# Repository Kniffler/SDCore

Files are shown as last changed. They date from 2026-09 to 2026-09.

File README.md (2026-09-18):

# SDCore
So I went and made an entire SD card because I thought my PicoCalc didn't have enough juice.

## IMPORTANT (READ THIS)
Please read through the entire README in order to get a grasp of the limitations of this project since they might save your skin while developing.

TL;DR: [Restrictions summary](#restrictions-summary)

### Also important
I am not responsible for your usage or misusage of this project.

## Specs
This SD core is based on the RP2350A by raspberry pi and features:
- Hardware-level control of the routing of the SD pins
- 3 state-indicating LEDs (power, program, and select)
- 16MiB of flash
- A micro-SD card slot
- Additional GPIO output (see below)
- An access point for USB programming when setting pin 6 to 3.3V

Annoyingly, when using the edge connector and the micro-SD card slot at the same time, no SPI interface will be left to use on the device, nor will the corresponding pins (see [pinout](#pinout)) be available for anything else.

# Images
None yet, we'll see when the order arrives.

# Hardware pin control
I added a tri-state demultiplexer ([NMUX27518EPWJ](https://assets.nexperia.com/documents/data-sheet/NMUX27518E.pdf)) to switch between 2 modes, direct transfer mode and sniffing mode (default is direct transfer mode). In direct transfer mode, the data0-data3, CLK and CMD pins from the edge connector are all mapped to the RP2350A and set up for communication via **SPI1**. While sniffing mode also maps the edge connector to the MCU, it does so via **SPI0** and also directs them towards the micro-SD card slot allowing the MCU to sniff/spy on the communication between the host device and the micro-SD card.

> [!IMPORTANT]
> When using direct transfer mode, SPI1 is used and in sniffing mode we use SPI0. The pinouts are inherently different. Please look at the [pinout](#pinout) section for details.

The different SPI controllers are utilized in order to communicate with the host and the micro-SD card separately and/or simultaneously.

# How to program the RP2350A
There are 2 main scenarios, either you have the programmer board, or you don't. In the case that you do, connect the USB-C port to your PC or laptop, plug the SD core into the programmer board while holding the button on the board, once you see the USB mass storage on your PC (which you have presumably plugged into the programmer board already) you can release the button.

If you do not own a programmer board, (though it is highly recommended that you do) you can order one with the given gerber, BOM and P&P files which can be found in the `SDCore_progBoard/prodution` folder which also holds a few key values for ordering with PCB Assembly on [JLCPCB](jlcpcb.com).

> [!NOTE]
> The `.zip` file is the compressed gerber files, `bom.csv` is the BOM and `positions.csv` is the P&P file.

If ordering this PCB is not an option, please continue in the subsection below.

## Making a programmer board at home
You'll need:
- A reliable 3.3V power source
- A switch
- A breakout board of any USB end (male or female, type-A or type-C, whichever you can use to plug into your PC) with a D- and a D+ pin. If there are multiple of each, short them such that you only have **one** D- and **one** D+
- A breakout board of a **standard SD card** with ALL of these pins present: 3 (VSS/GND), 4 (VDD/3V3), 6 (the magic pin), 8 (DAT1) and 9 (DAT2) - other pins are optional

> [!WARNING]
> If any of these SD pins are missing from the breakout, you will not be able to program your SDCore.

If you don't have an SD breakout, look have a look at [this](https://www.instructables.com/Cheap-DIY-SD-card-breadboard-socket/) article on how to make one with all the needed pins.

Now you connect it as follows (the pins refer to the SD breakout board):
1. GND to pin 3 (may also be labeled as VSS or GND)
2. 3.3V to pin 4 (may also be labeled as VDD, VCC or 3V3)
3. USB D- (data negative/minus) to pin 8 (may also be labeled as DATA1 or DAT1)
4. USB D+ (data negative/minus) to pin 9 (may also be labeled as DATA2 or DAT2)
5. Connect one end of the switch to 3.3V and the other to pin 6 (may also be labeled as VSS or GND)

You may leave all the other pins unconnected or tie them to GND.

Normally, pin 6 is an alternate GND pin, however the SD core uses it to signify the BOOTSEL function and boot into the USB mass storage bootloader. 
> [!WARNING]
> Using this setup for a regular SD card will lead to shorts when pressing the switch.

> [!CAUTION]
> This device does not support booting via UART, USB is currently the only supported boot form.

You can now plug this setup into your PC, enable the 3.3V source and connect the SD core while holding the switch. Once you see a USB mass storage device you may release the switch.

# Pinout
By default, the SD pins are configured to go to the MCU directly over the following pins:
```
Using SPI1
GPIO 8 - SPI1 MISO
GPIO 9 - SPI1 CSn
GPIO 10 - SPI1 CLK
GPIO 11 - SPI1 MOSI

GPIO 0 - DATA1 (pin 8)
GPIO 1 - DATA2 (pin 9)
```
in sniffing mode, they connect as follows:
```
Using SPI0
GPIO 4 - SPI0 MISO
GPIO 5 - SPI0 CSn
GPIO 6 - SPI0 CLK
GPIO 7 - SPI0 MOSI

GPIO 24 - DATA1 (pin 8)
GPIO 25 - DATA2 (pin 9)
```

The selection signal is controlled by GPIO 3 and is pulled down to GND with 10kΩ. Driving this signal high will put the demultiplexer into the sniffing mode pinout, whereas the direct mode's pinout becomes disconnected.

The connections/pins 3V3, GND, SWCLK, SWDIO, RUN, GPIO 2, GPIO 12-23 and GPIO 26-29 are exposed via a board-to-board connector on the SDCore. A breakout cable has not yet been added to this repo.

> [!CAUTION]
> The USB signals of the RP2350A are always connected to the DATA 1 and 2 pins.
> It is the user's responsibility to ensure the MCU does not read USB when it is not supposed to, this also means disabling stdio over USB ***and*** stdio over UART when not using the programmer board.

# Restrictions summary
1. The SD core takes up all of the SPI interfaces in certain use cases - avoid using SPI interfaces via the exposed GPIO pins
2. The SPI interface changes based on the state of the demultiplexer - switch SPI interface and pins when toggling GPIO 3
3. USB is always conntected to data pins 1 and 2, as such it may also be connected to GPIO pairs 24/25 or 0/1 - never use USB when the active GPIO pair may interfere
4. UART bootloader is inaccessible - only program via USB or custom software
5. Pin 6 is usually tied to ground by SD slots, meaning ground will only go through pin 3 - be sure to keep the current low to avoid burnout
6. The switch on the programmer board/circuit may not be pressed while a regular SD card is plugged in - avoid using the programmer board/circuit with regular SD cards
7. Power draw is severly limited due to the SD pad contact area - avoid powering more GPIOs than absolutely necessary or use an external 3.3V source for any additions (e.g. sensors)
8. ***Absolutely no overclocking***. Due to the power limits, drawing more than the slot allows may lead to melting of the contact pins and ruin your programmer board/circuit.

# Credits
All mine baby.

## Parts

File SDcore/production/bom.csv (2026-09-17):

Designator | Footprint | Quantity | Value | LCSC Part #
C1, C10, C11, C12, C13, C16, C5, C6, C7, C8, C9 | 0402B104K250NT | 11 | 100n | C56392
C14, C15 | 0402CG150J500NT | 2 | 15p | C1548
C2, C3, C4 | C1005X5R0J475MTJ00E | 3 | 4.7u | C23687
CARD1 | TF-009 | 1 | TF-009 | C428466
GPIO1 | JME-BB0009R24A | 1 | JME-BB0009R24A | C50087608
J1 | SD_Card_Device_16mm_SlotDepth | 1 | SD_Card_Device
L1 | AOTA-B201610S3R3-101-T | 1 | ~ | C42411119
LED1 | XL-1005SURC_C25503345 | 1 | Power_led | C25503345
LED2 | XL-1005UBC_C22355736 | 1 | Prog_led | C22355736
LED3 | 16-213_GHC-YR1S1_3T | 1 | SEL_led | C74338
Q1 | L2N7002WT1G | 1 | ~ | C12778
R1, R11, R12, R13, R14, R15, R16, R7 | CRCW040210K0FKED | 8 | 10k | C71617
R10, R4, R9 | CRCW040233R0FKED | 3 | 33 | C242490
R2, R3 | RT0402BRD0727RL | 2 | 27 | C852682
R5, R6 | CRCW04021K00FKED | 2 | 1k | C71623
R8 | ERJPA2F68R0X | 1 | 68 | C542959
U1 | RP2350A_C42411118 | 1 | RP2350A_C42411118 | C42411118
U2 | NMUX27518EPWJ | 1 | NMUX27518EPWJ | C50341769
U3 | W25Q128JVEIQ_TR | 1 | W25Q128JVEIQ_TR | C2456297
X1 | ABM8-272-T3_C20625731 | 1 | ABM8-272-T3_C20625731 | C20625731

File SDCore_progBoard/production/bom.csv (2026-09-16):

Designator | Footprint | Quantity | Value | LCSC Part #
C1, C2 | CL05A106MQ5NUNC | 2 | 10uF | C15525
CARD1 | SD-111 | 1 | SD-111 | C410353
H1 | HX_PZ2_0-1X10P_ZZ | 1 | HX_PZ2_0-1X10P_ZZ | C22438293
R1, R2 | 0603WAF5101T5E | 2 | 5.1k | C23186
SW1 | TS-1101-C-W | 1 | TS-1101-C-W | C318938
U1 | BL1117-33CX | 1 | BL1117-33CX | C5400
USB1 | USB-310 | 1 | USB-310 | C309347

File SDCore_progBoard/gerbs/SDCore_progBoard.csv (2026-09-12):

Id | Designator | Footprint | Quantity | Designation | Supplier and ref
1 | USB1 | TYPE-C-31-M-13 | 1 | TYPE-C-31-M-13
2 | U1 | BL1117-33CX | 1 | BL1117-33CX
3 | R2,R1 | 0603WAF5101T5E | 2 | 5.1k
4 | Card1 | DS1139-01-09SS4BSR | 1 | DS1139-01-09SS4BSR

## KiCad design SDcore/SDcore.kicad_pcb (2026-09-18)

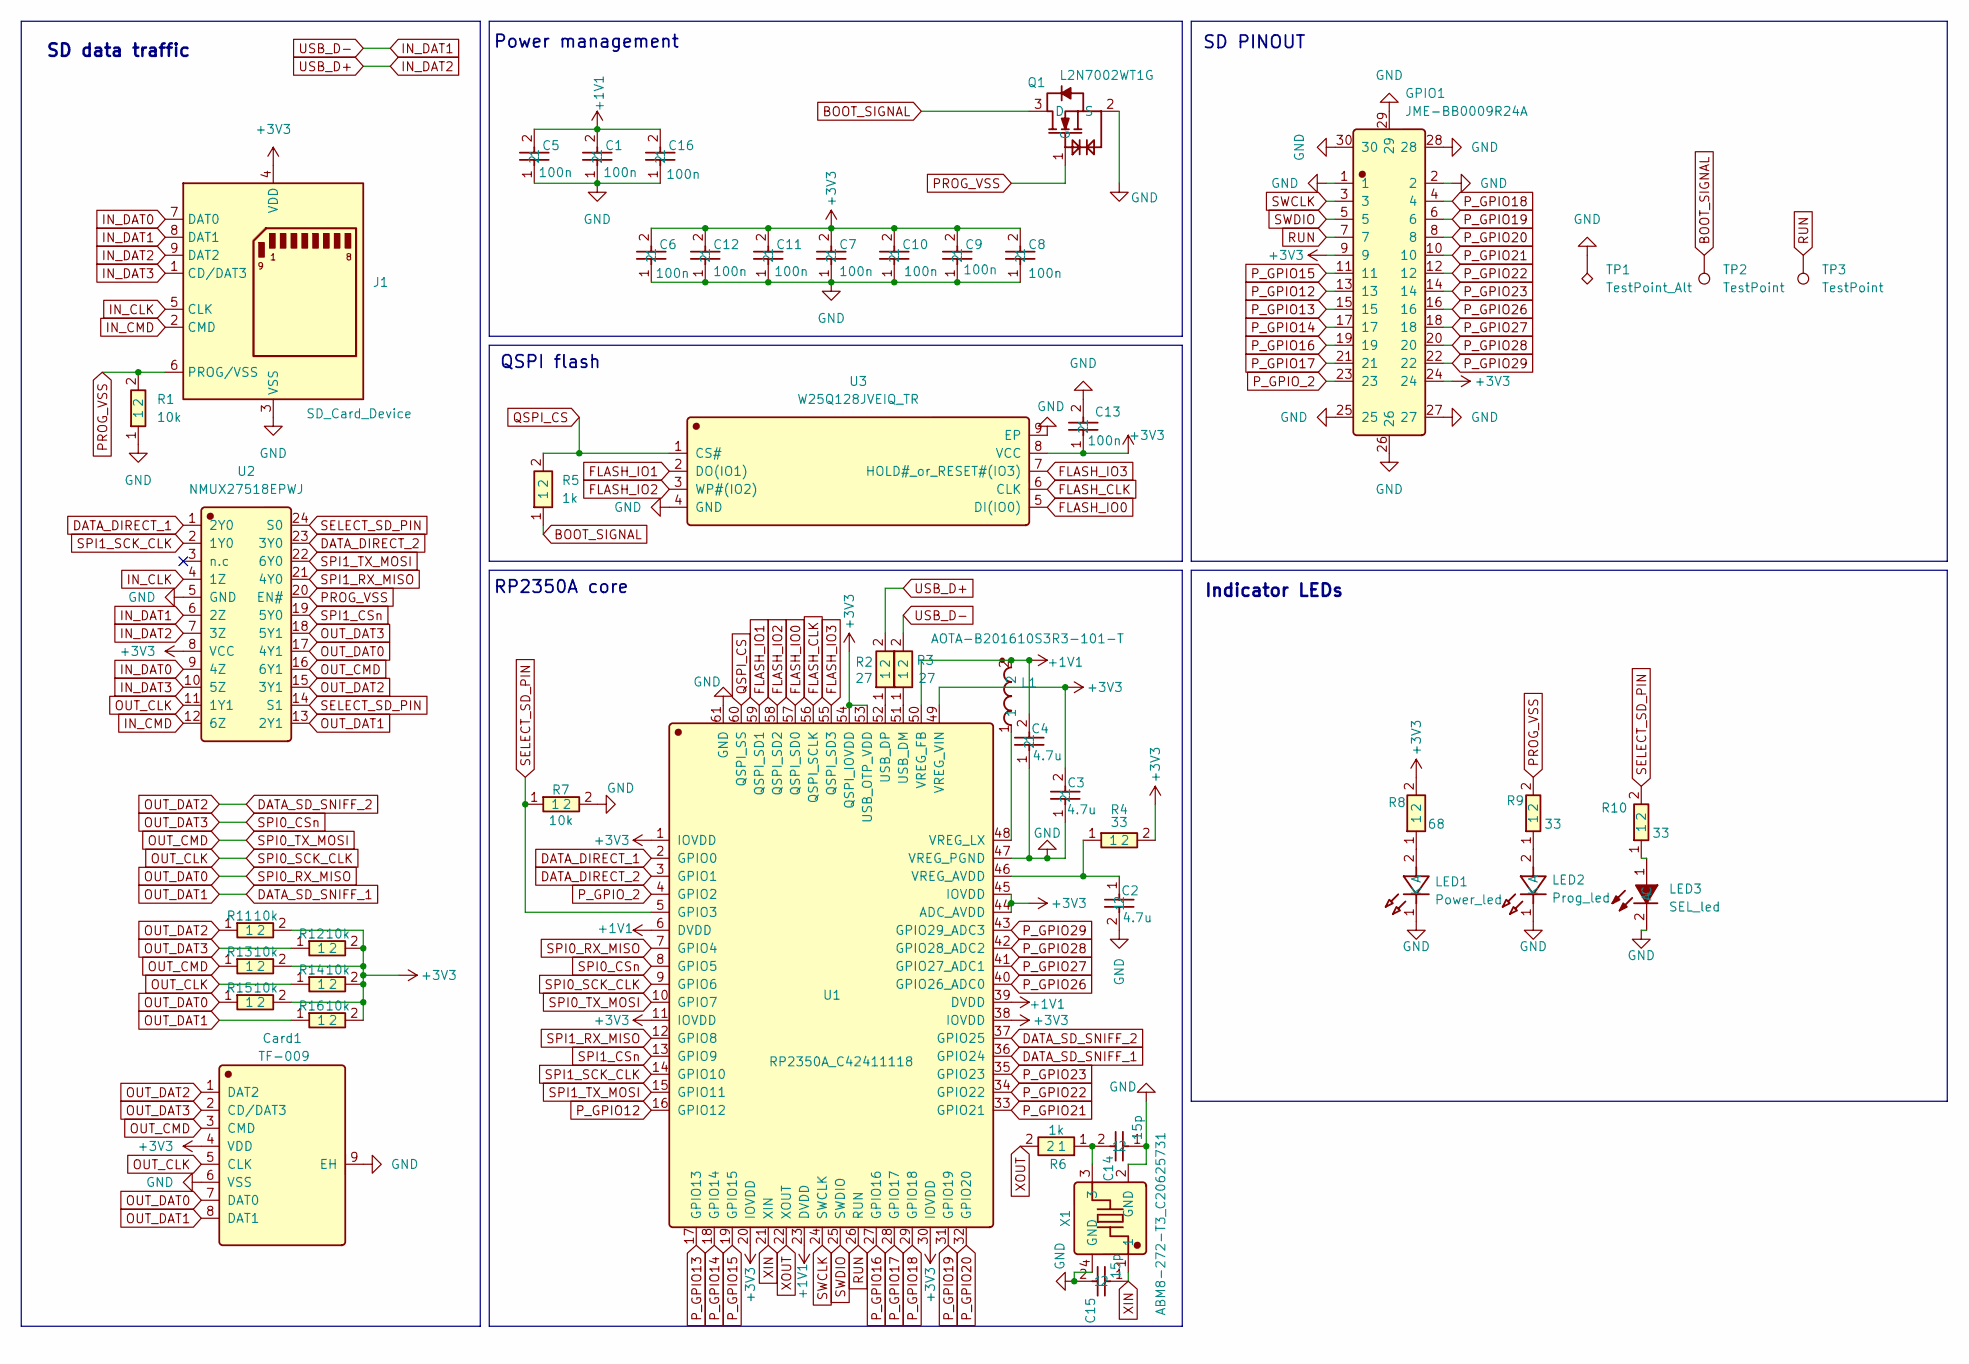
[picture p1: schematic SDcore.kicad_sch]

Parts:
C1, C5, C6, C7, C8, C9, C10, C11, C12, C13, C16: 100n; 0402B104K250NT; Manufacturer Part 0402B104K250NT; LCSC C56392
C2, C3, C4: 4.7u; C1005X5R0J475MTJ00E; Manufacturer Part C1005X5R0J475MTJ00E; LCSC C23687
C14, C15: 15p; 0402CG150J500NT; Manufacturer Part 0402CG150J500NT; LCSC C1548
Card1: TF-009; Manufacturer Part TF-009; LCSC C428466
GPIO1: JME-BB0009R24A; Manufacturer Part JME-BB0009R24A; LCSC C50087608
J1: SD_Card_Device; SD_Card_Device_16mm_SlotDepth
L1: AOTA-B201610S3R3-101-T; Manufacturer Part AOTA-B201610S3R3-101-T; LCSC C42411119
LED1: Power_led; XL-1005SURC_C25503345; Manufacturer Part XL-1005SURC; LCSC C25503345
LED2: Prog_led; XL-1005UBC_C22355736; Manufacturer Part XL-1005UBC; LCSC C22355736
LED3: SEL_led; 16-213_GHC-YR1S1_3T; Manufacturer Part 16-213/GHC-YR1S1/3T; LCSC C74338
Q1: L2N7002WT1G; Manufacturer Part L2N7002WT1G; LCSC C12778
R1, R7, R11, R12, R13, R14, R15, R16: 10k; CRCW040210K0FKED; Manufacturer Part CRCW040210K0FKED; LCSC C71617
R2, R3: 27; RT0402BRD0727RL; Manufacturer Part RT0402BRD0727RL; LCSC C852682
R4, R9, R10: 33; CRCW040233R0FKED; Manufacturer Part CRCW040233R0FKED; LCSC C242490
R5, R6: 1k; CRCW04021K00FKED; Manufacturer Part CRCW04021K00FKED; LCSC C71623
R8: 68; ERJPA2F68R0X; Manufacturer Part ERJPA2F68R0X; LCSC C542959
TP1: TestPoint_Alt; TestPoint_Pad_1.0x1.0mm
TP2, TP3: TestPoint; TestPoint_Pad_D1.0mm
U1: RP2350A_C42411118; Manufacturer Part RP2350A; LCSC C42411118
U2: NMUX27518EPWJ; Manufacturer Part NMUX27518EPWJ; LCSC C50341769
U3: W25Q128JVEIQ_TR; Manufacturer Part W25Q128JVEIQ TR; LCSC C2456297
X1: ABM8-272-T3_C20625731; Manufacturer Part ABM8-272-T3; LCSC C20625731

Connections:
+1V1: C1.2, C4.2, C5.2, C16.2, L1.2, U1.6 (DVDD), U1.23 (DVDD), U1.39 (DVDD), U1.50 (VREG_FB)
+3V3: C3.2, C6.2, C7.2, C8.2, C9.2, C10.2, C11.2, C12.2, C13.1, Card1.4 (VDD), GPIO1.9, GPIO1.24, J1.4 (VDD), R4.2, R8.2, R11.2, R12.2, R13.2, R14.2, R15.2, R16.2, U1.1 (IOVDD), U1.11 (IOVDD), U1.20 (IOVDD), U1.30 (IOVDD), U1.38 (IOVDD), U1.44 (ADC_AVDD), U1.45 (IOVDD), U1.49 (VREG_VIN), U1.53 (USB_OTP_VDD), U1.54 (QSPI_IOVDD), U2.8 (VCC), U3.8 (VCC)
BOOT_SIGNAL: Q1.3 (D), R5.1, TP2.1
DATA_DIRECT_1: U1.2 (GPIO0), U2.1 (2Y0)
DATA_DIRECT_2: U1.3 (GPIO1), U2.23 (3Y0)
DATA_SD_SNIFF_1: Card1.8 (DAT1), R16.1, U1.36 (GPIO24), U2.13 (2Y1)
DATA_SD_SNIFF_2: Card1.1 (DAT2), R11.1, U1.37 (GPIO25), U2.15 (3Y1)
FLASH_CLK: U1.56 (QSPI_SCLK), U3.6 (CLK)
FLASH_IO0: U1.57 (QSPI_SD0), U3.5 (DI(IO0))
FLASH_IO1: U1.59 (QSPI_SD1), U3.2 (DO(IO1))
FLASH_IO2: U1.58 (QSPI_SD2), U3.3 (WP#(IO2))
FLASH_IO3: U1.55 (QSPI_SD3), U3.7 (HOLD#_or_RESET#(IO3))
GND: C1.1, C2.2, C3.1, C4.1, C5.1, C6.1, C7.1, C8.1, C9.1, C10.1, C11.1, C12.1, C13.2, C14.1, C15.2, C16.1, Card1.6 (VSS), Card1.9 (EH), GPIO1.1, GPIO1.2, GPIO1.25, GPIO1.26, GPIO1.27, GPIO1.28, GPIO1.29, GPIO1.30, J1.3 (VSS), LED1.1 (K), LED2.1 (K), LED3.2 (C), Q1.2 (S), R1.1, R7.2, TP1.1, U1.47 (VREG_PGND), U1.61 (GND), U2.5 (GND), U3.4 (GND), U3.9 (EP), X1.2 (GND), X1.4 (GND)
IN_CLK: J1.5 (CLK), U2.4 (1Z)
IN_CMD: J1.2 (CMD), U2.12 (6Z)
IN_DAT0: J1.7 (DAT0), U2.9 (4Z)
IN_DAT1: J1.8 (DAT1), R3.2, U2.6 (2Z)
IN_DAT2: J1.9 (DAT2), R2.2, U2.7 (3Z)
IN_DAT3: J1.1 (CD/DAT3), U2.10 (5Z)
unnamed: C14.2, R6.1, X1.3
unnamed: LED1.2 (A), R8.1
unnamed: LED2.2 (A), R9.1
unnamed: LED3.1 (A), R10.1
unnamed: R3.1, U1.51 (USB_DM)
unnamed: R2.1, U1.52 (USB_DP)
unnamed: C2.1, R4.1, U1.46 (VREG_AVDD)
unnamed: L1.1, U1.48 (VREG_LX)
OUT_CLK: Card1.5 (CLK), R14.1, U1.9 (GPIO6), U2.11 (1Y1)
OUT_CMD: Card1.3 (CMD), R13.1, U1.10 (GPIO7), U2.16 (6Y1)
OUT_DAT0: Card1.7 (DAT0), R15.1, U1.7 (GPIO4), U2.17 (4Y1)
OUT_DAT3: Card1.2 (CD/DAT3), R12.1, U1.8 (GPIO5), U2.18 (5Y1)
PROG_VSS: J1.6 (PROG/VSS), Q1.1 (G), R1.2, R9.2, U2.20 (EN#)
P_GPIO12: GPIO1.13, U1.16 (GPIO12)
P_GPIO13: GPIO1.15, U1.17 (GPIO13)
P_GPIO14: GPIO1.17, U1.18 (GPIO14)
P_GPIO15: GPIO1.11, U1.19 (GPIO15)
P_GPIO16: GPIO1.19, U1.27 (GPIO16)
P_GPIO17: GPIO1.21, U1.28 (GPIO17)
P_GPIO18: GPIO1.4, U1.29 (GPIO18)
P_GPIO19: GPIO1.6, U1.31 (GPIO19)
P_GPIO20: GPIO1.8, U1.32 (GPIO20)
P_GPIO21: GPIO1.10, U1.33 (GPIO21)
P_GPIO22: GPIO1.12, U1.34 (GPIO22)
P_GPIO23: GPIO1.14, U1.35 (GPIO23)
P_GPIO26: GPIO1.16, U1.40 (GPIO26_ADC0)
P_GPIO27: GPIO1.18, U1.41 (GPIO27_ADC1)
P_GPIO28: GPIO1.20, U1.42 (GPIO28_ADC2)
P_GPIO29: GPIO1.22, U1.43 (GPIO29_ADC3)
P_GPIO_2: GPIO1.23, U1.4 (GPIO2)
QSPI_CS: R5.2, U1.60 (QSPI_SS), U3.1 (CS#)
RUN: GPIO1.7, TP3.1, U1.26 (RUN)
SELECT_SD_PIN: R7.1, R10.2, U1.5 (GPIO3), U2.14 (S1), U2.24 (S0)
SPI1_CSn: U1.13 (GPIO9), U2.19 (5Y0)
SPI1_RX_MISO: U1.12 (GPIO8), U2.21 (4Y0)
SPI1_SCK_CLK: U1.14 (GPIO10), U2.2 (1Y0)
SPI1_TX_MOSI: U1.15 (GPIO11), U2.22 (6Y0)
SWCLK: GPIO1.3, U1.24 (SWCLK)
SWDIO: GPIO1.5, U1.25 (SWDIO)
XIN: C15.1, U1.21 (XIN), X1.1
XOUT: R6.2, U1.22 (XOUT)

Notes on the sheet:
Indicator LEDs
SD PINOUT
SD data traffic
Power management
RP2350A core
QSPI flash

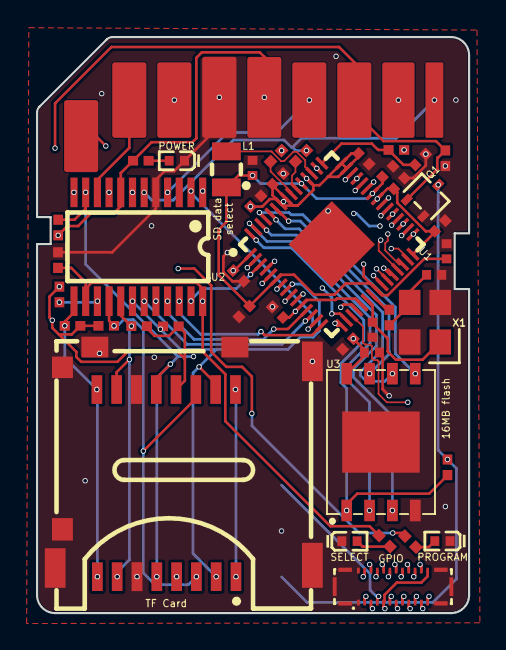
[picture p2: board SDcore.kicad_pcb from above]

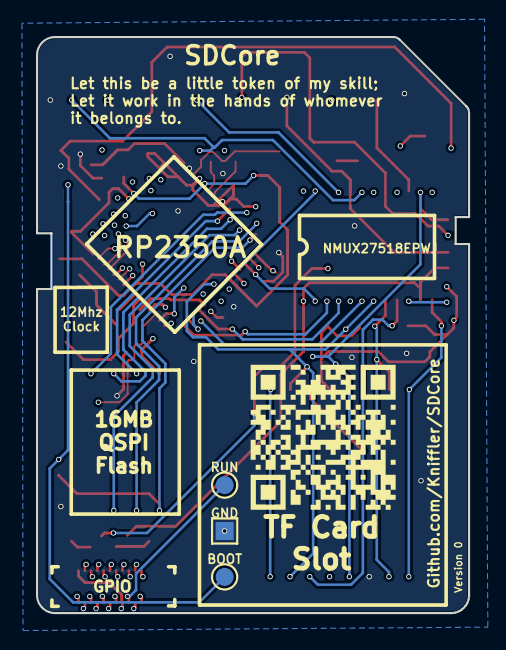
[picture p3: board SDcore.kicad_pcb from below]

Board: 4 copper layers, 24.0 x 32.0 mm, 47 parts (3 on the bottom side), 60 nets.

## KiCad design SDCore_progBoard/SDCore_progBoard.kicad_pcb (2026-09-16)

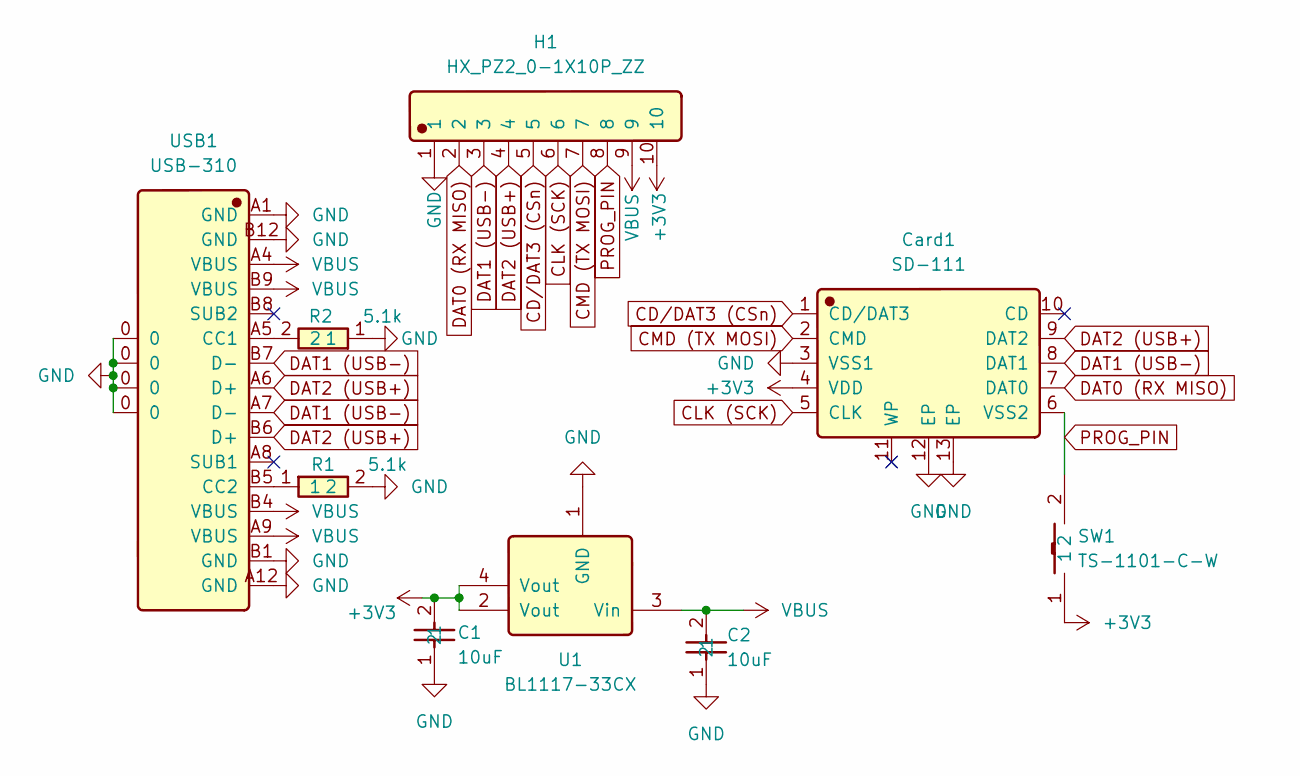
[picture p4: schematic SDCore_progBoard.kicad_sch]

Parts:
C1, C2: 10uF; CL05A106MQ5NUNC; Manufacturer Part CL05A106MQ5NUNC; LCSC C15525
Card1: SD-111; Manufacturer Part SD-111; LCSC C410353
H1: HX_PZ2_0-1X10P_ZZ; Manufacturer Part HX PZ2.0-1x10P ZZ; LCSC C22438293
R1, R2: 5.1k; 0603WAF5101T5E; Manufacturer Part 0603WAF5101T5E; LCSC C23186
SW1: TS-1101-C-W; Manufacturer Part TS-1101-C-W; LCSC C318938
U1: BL1117-33CX; Manufacturer Part BL1117-33CX; LCSC C5400
USB1: USB-310; Manufacturer Part USB-310-B-SU; LCSC C309347

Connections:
+3V3: C1.2, Card1.4 (VDD), H1.10, SW1.1, U1.2 (Vout), U1.4 (Vout)
CD/DAT3 (CSn): Card1.1 (CD/DAT3), H1.5
CLK (SCK): Card1.5 (CLK), H1.6
CMD (TX MOSI): Card1.2 (CMD), H1.7
DAT0 (RX MISO): Card1.7 (DAT0), H1.2
DAT1 (USB-): Card1.8 (DAT1), H1.3, USB1.A7 (D-), USB1.B7 (D-)
DAT2 (USB+): Card1.9 (DAT2), H1.4, USB1.A6 (D+), USB1.B6 (D+)
GND: C1.1, C2.1, Card1.3 (VSS1), Card1.12 (EP), Card1.13 (EP), H1.1, R1.2, R2.1, U1.1 (GND), USB1.0, USB1.A1 (GND), USB1.A12 (GND), USB1.B1 (GND), USB1.B12 (GND)
unnamed: R2.2, USB1.A5 (CC1)
unnamed: R1.1, USB1.B5 (CC2)
PROG_PIN: Card1.6 (VSS2), H1.8, SW1.2
VBUS: C2.2, H1.9, U1.3 (Vin), USB1.A4 (VBUS), USB1.A9 (VBUS), USB1.B4 (VBUS), USB1.B9 (VBUS)

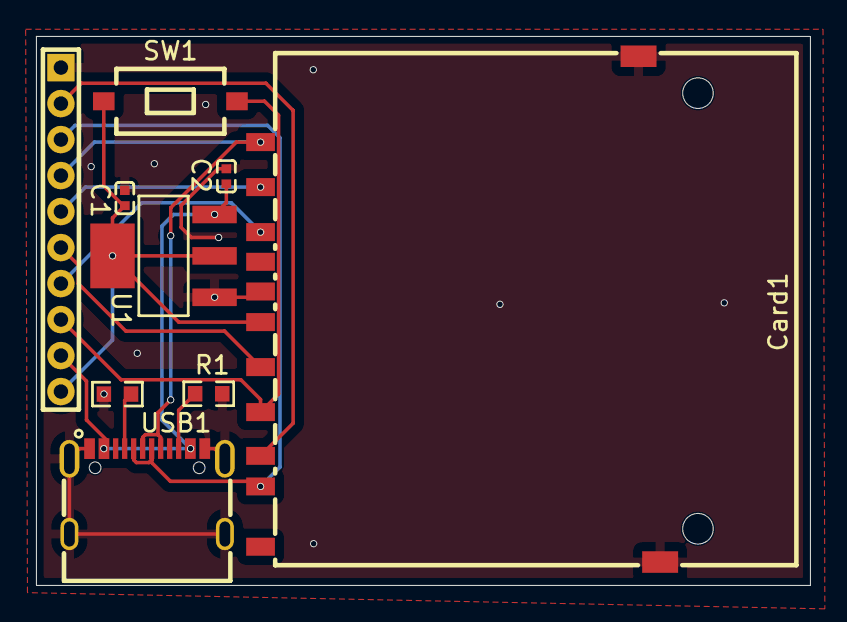
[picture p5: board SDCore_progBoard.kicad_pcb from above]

Board: 2 copper layers, 43.0 x 30.5 mm, 9 parts (0 on the bottom side), 12 nets.

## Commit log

2026-09-12 I added the basics
    [SDCore_progBoard-B_Cu.gbl, SDCore_progBoard-B_Cu.gbr, SDCore_progBoard-B_Mask.gbr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]
2026-09-13 Updated BOOTSEL logic
    [SDCore_progBoard.kicad_pcb, SDCore_progBoard.kicad_sch, SDcore.kicad_pcb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]
2026-09-13 Updated schematics and PCB, rewired some GPIOs
    [SDcore.kicad_pcb, SDcore.kicad_sch, bom.csv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]
2026-09-14 More light changes
    [SDCore_progBoard-B_Cu.gbl, SDCore_progBoard-B_Mask.gbs, SDCore_progBoard-B_Paste.gbp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]
2026-09-14 Added pull-up resistors to the micro-SD card slot
    [SDcore.kicad_pcb, SDcore.kicad_sch, bom.csv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]
2026-09-15 Added more clearance on some pads. Updated footprint of the SD card to set the WP notch to unlocked
    [SDcore.kicad_pcb, positions.csv]
2026-09-15 Frogot to update board thickness
    [SDcore.kicad_pcb]
2026-09-15 Added clearings on the side like an actual SD card
    [SDcore.kicad_pcb]
2026-09-16 Changed entirety of the progboard design to include a pin header, to make this devboard actually useful
    [SDCore_progBoard.kicad_pcb, SDCore_progBoard.kicad_sch, bom.csv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]
2026-09-16 Updated production files
    [positions.csv]
2026-09-17 Adjusted pad size of edge connector; Added clearance between pads of 0.2mm in order to comply with manufacturer capabilities
    [SDcore.kicad_pcb, bom.csv, positions.csv]
2026-09-18 I forgot that traces have clearances too, so I added them; Added test pads for reset and bootsel functions; Removed ground zone underneath MCU to reduce potential interference.
    [SDcore.kicad_pcb, SDcore.kicad_sch]
